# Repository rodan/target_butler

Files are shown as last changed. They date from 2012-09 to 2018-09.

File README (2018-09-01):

  Target butler is an archery-related project that tries to 'read' the arrow score based on sound and vibration sensor readouts.
  4 sensors (microphones) are surrounding the target itself, each of the 4 channels are amplified and the resulting signal passes thru an envelope-detection circuit. the 4 ADC values are read at a ~1ms interval by the uC.
  power is either from a 2Ah LiPo accu, any random 5V source or a solar panel.

  this project has not reached a 'working' stage. the sensors need to be changed to something that has a more omni-directional quality.

  Library dependencies for the included avr software:

  rfm12b      http://jeelabs.org/2009/02/10/rfm12b-library-for-arduino/
  sdfatlib    http://code.google.com/p/sdfatlib/

  dependencies for the server-side software:

  // not written yet

  Author:          Petre Rodan <2b4eda@subdimension.ro>
  Available from:  https://github.com/rodan/target_butler
  License:         GNU GPLv3

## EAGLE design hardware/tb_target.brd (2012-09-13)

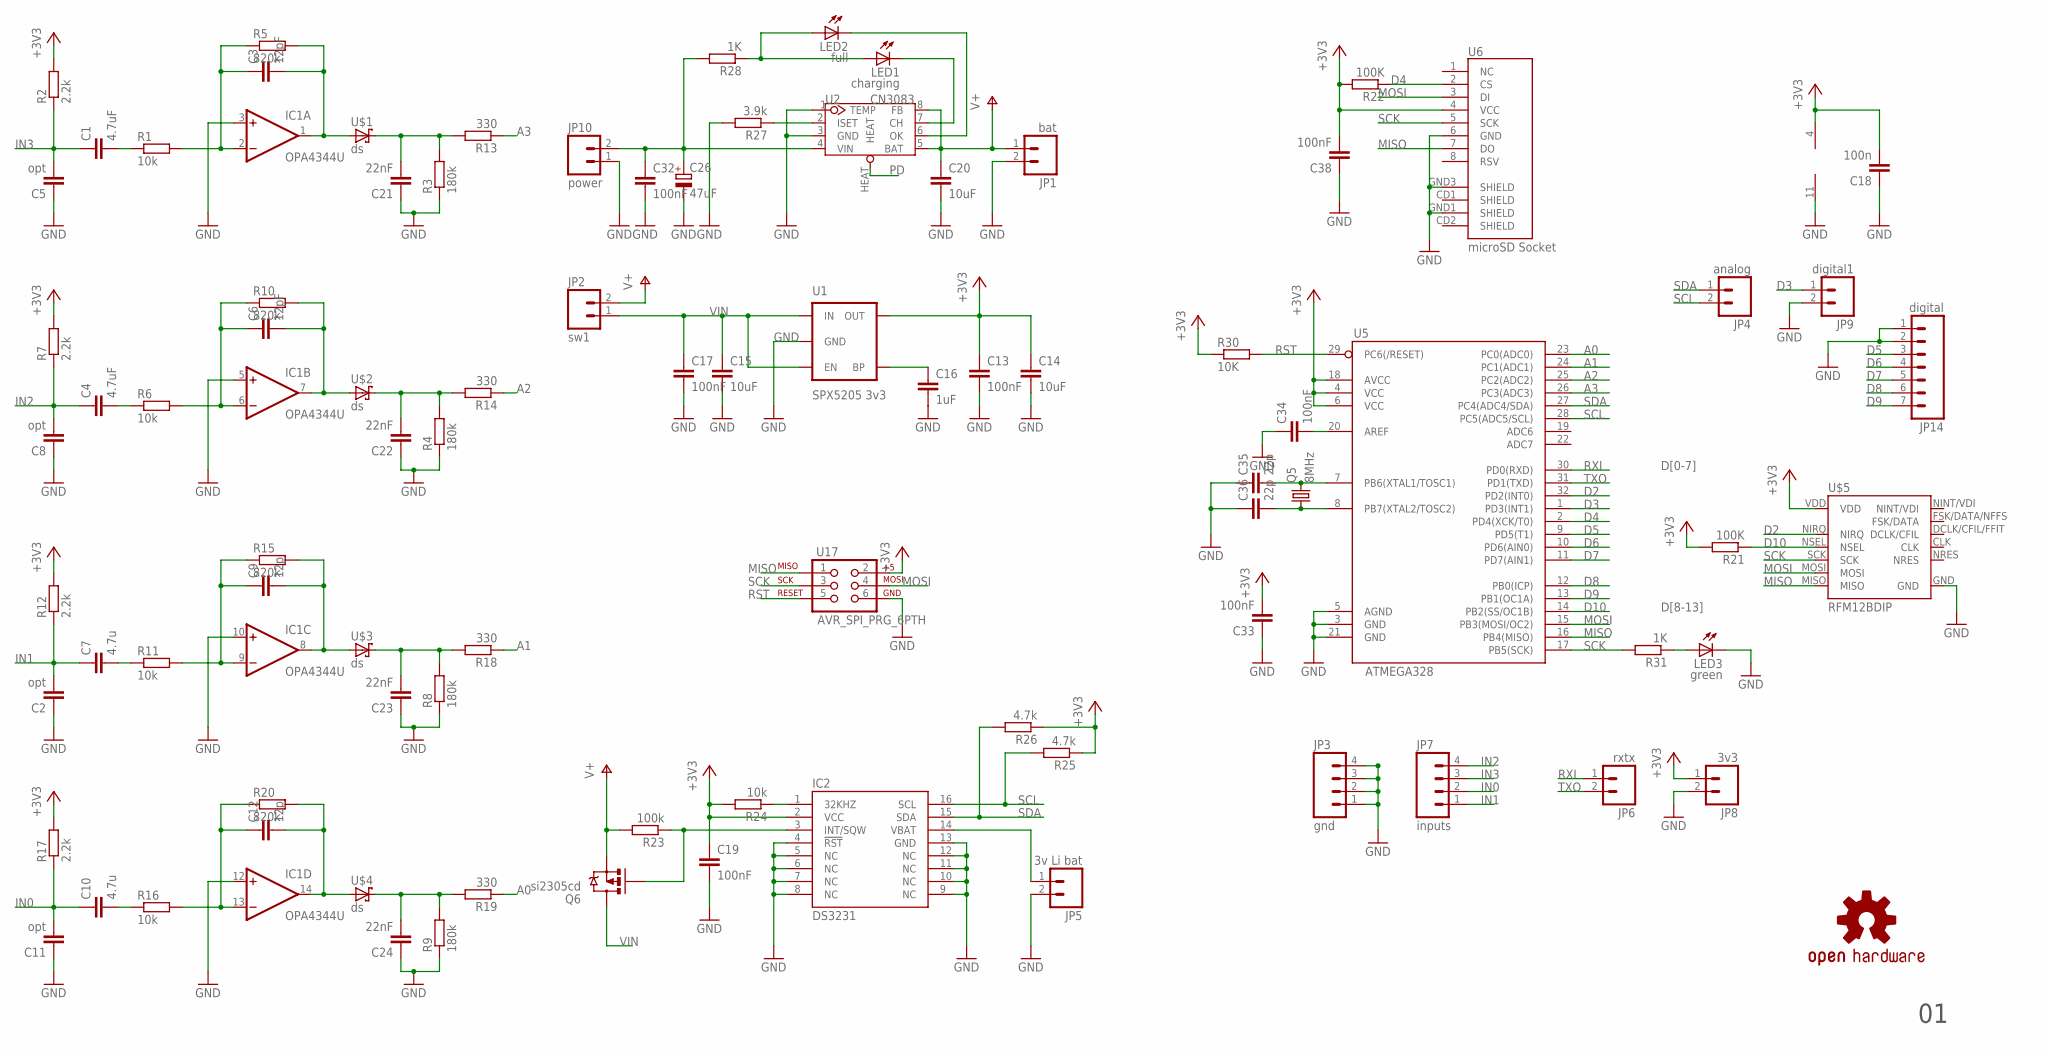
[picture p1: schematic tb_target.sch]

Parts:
C1, C4: 4.7uF; C0805
C2, C5, C8, C11: opt; C0805
C3, C6: 12pF; C0805
C7, C10: 4.7u; C0805
C9, C12: 12p; C0805
C13, C17, C19, C32, C33, C34, C38: 100nF; C0805
C14, C15, C20: 10uF; C1206
C16: 1uF; C0805
C18: 100n; C0805
C21, C22, C23, C24: 22nF; C0805
C26: 47uF; CT7343
C35, C36: 22p; C0805
IC1: OPA4344U; SO14
IC2: DS3231; SO-16
JP1: bat; 1X02
JP2: sw1; 1X02
JP3: gnd; 1X04
JP4: analog; 1X02
JP5: 3v Li bat; 1X02
JP6: rxtx; 1X02
JP7: inputs; 1X04
JP8: 3v3; 1X02
JP9: digital1; 1X02
JP10: power; 1X02
JP14: digital; 1X07
LED1: charging; CHIP-LED0805
LED2: full; CHIP-LED0805
LED3: green; CHIP-LED0805
Q5: 8MHz; CRYSTAL_5X3.2
Q6: si2305cd; SOT23-3_POWER
R1, R6, R11, R16, R24: 10k; R0805W
R2, R7, R12, R17: 2.2k; R0805W
R3, R4, R8, R9: 180k; R0805W
R5, R10, R15, R20: 820k; R0805W
R13, R14, R18, R19: 330; R0805W
R21, R22: 100K; R0805W
R23: 100k; R0805W
R25, R26: 4.7k; R0805W
R27: 3.9k; R0805W
R28, R31: 1K; R0805W
R30: 10K; R0805W
U1: SPX5205 3v3; SOT23-5
U2: CN3083; SOP8-W/-HEAT
U5: ATMEGA328; TQFP32-08
U6: microSD Socket; MICRO-SD-SOCKET-PP
U17: AVR_SPI_PRG_6PTH; 2X3
U$1, U$2, U$3, U$4: ds; SOD80
U$5: RFM12BDIP; RFM12B_DIP
U$7: OSHW-LOGOM; OSHW-LOGO-M

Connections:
+3V3: C13.1, C14.1, C18.2, C19.1, C33.2, C38.2, IC1.4 (V+), IC2.2 (VCC), JP8.1, R2.2, R7.2, R12.2, R17.2, R21.2, R22.2, R24.2, R25.1, R26.1, R30.1, U1.5 (OUT), U5.4 (VCC), U5.6 (VCC), U5.18 (AVCC), U6.4 (VCC), U17.2, U$5.VDD
A0: R19.1, U5.23 (PC0(ADC0))
A0D: C24.2, R9.2, R19.2, U$4.C
A1: R18.1, U5.24 (PC1(ADC1))
A1D: C23.2, R8.2, R18.2, U$3.C
A2: R14.1, U5.25 (PC2(ADC2))
A2D: C22.2, R4.2, R14.2, U$2.C
A2E: C6.2, IC1.7 (OUT), R10.2, U$2.A
A3: R13.1, U5.26 (PC3(ADC3))
A3D: C21.2, R3.2, R13.2, U$1.C
D2: U5.32 (PD2(INT0)), U$5.NIRQ
D3: JP9.1, U5.1 (PD3(INT1))
D4: R22.1, U5.2 (PD4(XCK/T0)), U6.2 (CS)
D5: JP14.3, U5.9 (PD5(T1))
D6: JP14.4, U5.10 (PD6(AIN0))
D7: JP14.5, U5.11 (PD7(AIN1))
D8: JP14.6, U5.12 (PB0(ICP))
D9: JP14.7, U5.13 (PB1(OC1A))
D10: R21.1, U5.14 (PB2(SS/OC1B)), U$5.NSEL
GND: C2.1, C5.1, C8.1, C11.1, C13.2, C14.2, C15.2, C16.2, C17.2, C18.1, C19.2, C20.2, C21.1, C22.1, C23.1, C24.1, C26.-, C32.2, C33.1, C34.1, C35.1, C36.1, C38.1, IC1.3 (+IN), IC1.5 (+IN), IC1.10 (+IN), IC1.11 (V-), IC1.12 (+IN), IC2.4 (!RST), IC2.5 (NC), IC2.6 (NC), IC2.7 (NC), IC2.8 (NC), IC2.9 (NC), IC2.10 (NC), IC2.11 (NC), IC2.12 (NC), IC2.13 (GND), JP1.2, JP3.1, JP3.2, JP3.3, JP3.4, JP5.2, JP8.2, JP9.2, JP10.1, JP14.1, JP14.2, LED3.C, R3.1, R4.1, R8.1, R9.1, R27.2, U1.2 (GND), U2.1 (TEMP), U2.3 (GND), U5.3 (GND), U5.5 (AGND), U5.21 (GND), U6.6 (GND), U6.GND1 (SHIELD), U6.GND3 (SHIELD), U17.6, U$5.GND
IN0: C10.1, C11.2, JP7.2, R17.1
IN1: C2.2, C7.1, JP7.1, R12.1
IN2: C4.1, C8.2, JP7.4, R7.1
IN3: C1.1, C5.2, JP7.3, R2.1
MISO: U5.16 (PB4(MISO)), U6.7 (DO), U17.1, U$5.MISO
MOSI: U5.15 (PB3(MOSI/OC2)), U6.3 (DI), U17.4, U$5.MOSI
unnamed: C16.1, U1.4 (BP)
unnamed: C1.2, R1.1
unnamed: C3.1, IC1.2 (-IN), R1.2, R5.1
unnamed: IC2.1 (32KHZ), R24.1
unnamed: IC2.3 (INT/SQW), Q6.1 (G), R23.1
unnamed: C4.2, R6.1
unnamed: C6.1, IC1.6 (-IN), R6.2, R10.1
unnamed: IC2.14 (VBAT), JP5.1
unnamed: R27.1, U2.2 (ISET)
unnamed: C7.2, R11.1
unnamed: C9.1, IC1.9 (-IN), R11.2, R15.1
unnamed: C26.+, C32.1, JP10.2, R28.2, U2.4 (VIN)
unnamed: LED1.A, LED2.A, R28.1
unnamed: C10.2, R16.1
unnamed: C12.1, IC1.13 (-IN), R16.2, R20.1
unnamed: LED1.C, U2.7 (CH)
unnamed: LED2.C, U2.6 (OK)
unnamed: C36.2, Q5.P$1 (1), U5.8 (PB7(XTAL2/TOSC2))
unnamed: C35.2, Q5.P$2 (2), U5.7 (PB6(XTAL1/TOSC1))
unnamed: C34.2, U5.20 (AREF)
unnamed: LED3.A, R31.1
unnamed: C3.2, IC1.1 (OUT), R5.2, U$1.A
unnamed: C9.2, IC1.8 (OUT), R15.2, U$3.A
unnamed: C12.2, IC1.14 (OUT), R20.2, U$4.A
PD: U2.HEAT
RST: R30.2, U5.29 (PC6(/RESET)), U17.5
RXI: JP6.1, U5.30 (PD0(RXD))
SCK: R31.2, U5.17 (PB5(SCK)), U6.5 (SCK), U17.3, U$5.SCK
SCL: IC2.16 (SCL), JP4.2, R25.2, U5.28 (PC5(ADC5/SCL))
SDA: IC2.15 (SDA), JP4.1, R26.2, U5.27 (PC4(ADC4/SDA))
TXO: JP6.2, U5.31 (PD1(TXD))
V+: C20.1, JP1.1, JP2.2, Q6.2 (S), R23.2, U2.5 (BAT), U2.8 (FB)
VIN: C15.1, C17.1, JP2.1, Q6.3 (D), U1.1 (IN), U1.3 (EN)

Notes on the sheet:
D[0-7]
D[8-13]

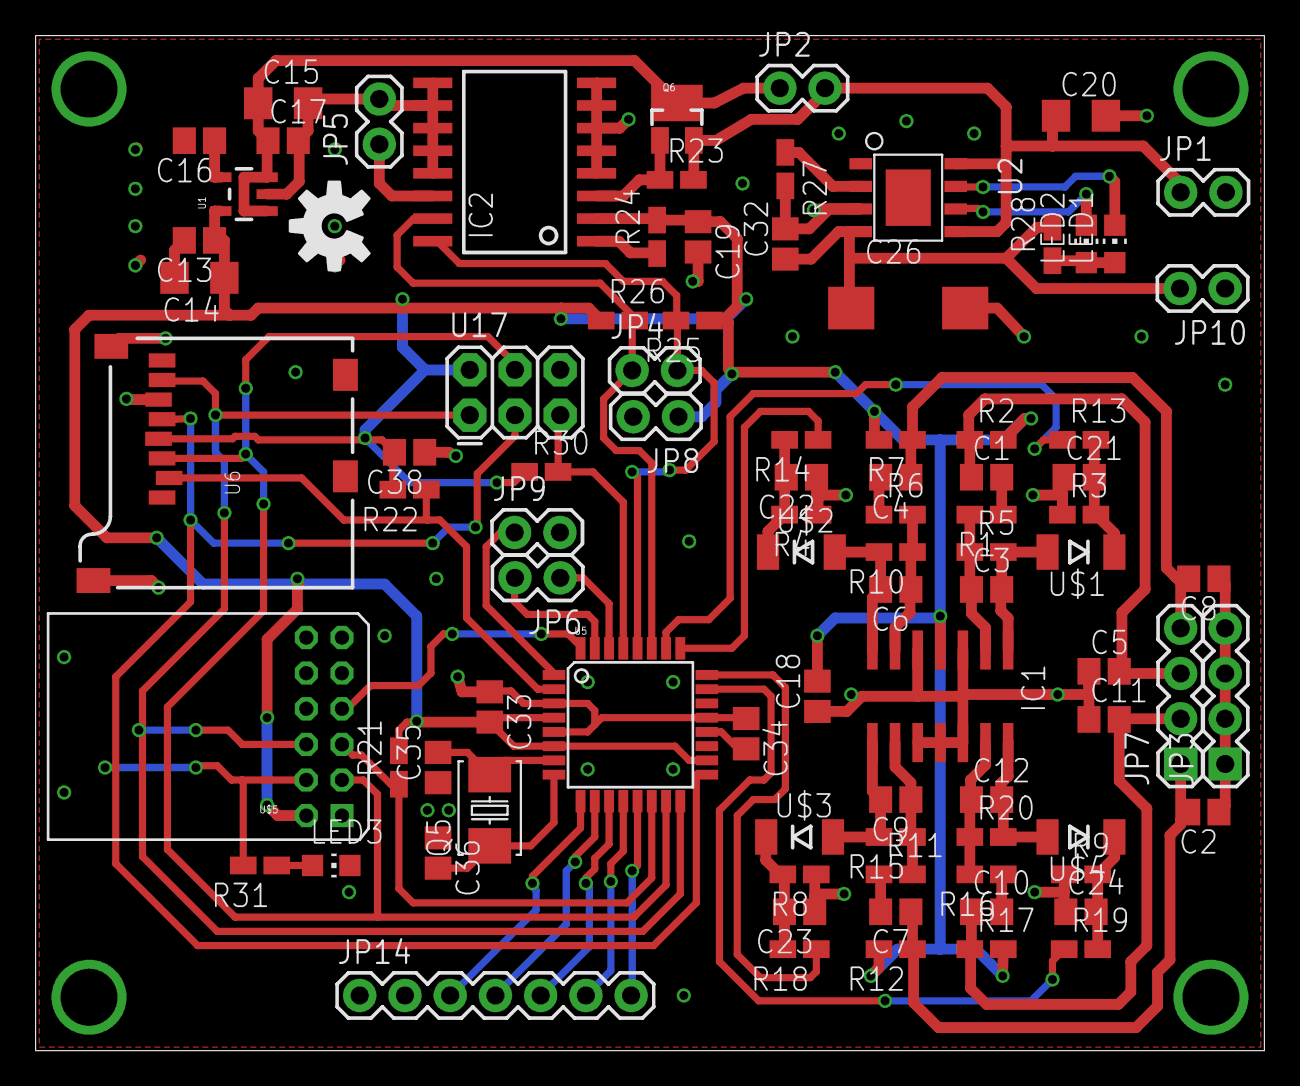
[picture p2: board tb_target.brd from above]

Board: 2 copper layers, 69.0 x 57.0 mm, 90 parts (0 on the bottom side), 58 nets.

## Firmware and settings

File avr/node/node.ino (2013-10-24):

#include <avr/wdt.h>
#include <SPI.h>
#include <SdFat.h>
#include <SdFatUtil.h>

//from jeelabs.org
#include <RF12.h>
#include <Ports.h>

#include "tb.h"

#define NODE_ID 10 // 0 to 29
#define FASTADC 0

#define pin_s0 A0
#define pin_s1 A1
#define pin_s2 A2
#define pin_s3 A3
#define pin_sd_cs 4

payload_result p;
payload_channel sen[4];

SdFat sd;
SdFile f;

int sample_delay = 1;

int threshold = 10;

// when to actually trigger the conversion
boolean adc_trigger = false;

// ADC conversion timeouts
unsigned long adc_conv_next = 2000;
// if a delay is needed before trigger computation
unsigned long adc_conv_trigger_timeout = 0;
unsigned long adc_delay_between_triggers = 400;

// USART timeouts
unsigned long refresh_prev = 0;
unsigned long refresh_delay = 400;

void discharge_inputs()
{
    // discharge the capacitor used for envelope detection
    pinMode(pin_s0, OUTPUT);
    pinMode(pin_s1, OUTPUT);
    pinMode(pin_s2, OUTPUT);
    pinMode(pin_s3, OUTPUT);
    digitalWrite(pin_s0, LOW);
    digitalWrite(pin_s1, LOW);
    digitalWrite(pin_s2, LOW);
    digitalWrite(pin_s3, LOW);
    delay(2);

    // go back into listening mode
    pinMode(pin_s0, INPUT);
    pinMode(pin_s1, INPUT);
    pinMode(pin_s2, INPUT);
    pinMode(pin_s3, INPUT);
}

void setup()
{
    uint8_t i;
    wdt_enable(WDTO_8S);

    delay(200); // allow 3v3 caps to fill up

    Serial.begin(9600);

#if FASTADC
    // set prescale to 16
    sbi(ADCSRA, ADPS2);
    cbi(ADCSRA, ADPS1);
    cbi(ADCSRA, ADPS0);
#endif

    if (!sd.init(SPI_HALF_SPEED, pin_sd_cs)) {
        Serial.println("ERR sd.init failed");
    }

    rf12_initialize(NODE_ID,freq,network);

    discharge_inputs();

    Serial.print("target butler node ");
    Serial.print(NODE_ID);
    Serial.println(" started");
    //Serial.println(sizeof p);

    p.node_id = NODE_ID;
    p.hit_id = 0;
    p.instant_en = 0;
    p.packet_type = PKT_RESULT;

    for (i=0; i<4; i++) {
        sen[i].packet_type = PKT_CHANNEL;
        sen[i].node_id = NODE_ID;
    }
}

void read_instant_en()
{
    p.instant_en =
        analogRead(pin_s0) + analogRead(pin_s1) + analogRead(pin_s2) + analogRead(pin_s3);

    discharge_inputs();
}

void read_inputs_multi()
{
    uint8_t i;

    for (i = 0; i < samples; i++) {
        sen[0].s[i] = analogRead(pin_s0);
        sen[1].s[i] = analogRead(pin_s1);
        sen[2].s[i] = analogRead(pin_s2);
        sen[3].s[i] = analogRead(pin_s3);
        //delay(sample_delay);
    }

    p.s_en[0] = 0;
    p.s_en[1] = 0;
    p.s_en[2] = 0;
    p.s_en[3] = 0;

    for (i = 0; i < samples; i++) {
        p.s_en[0] += sen[0].s[i];
        p.s_en[1] += sen[1].s[i];
        p.s_en[2] += sen[2].s[i];
        p.s_en[3] += sen[3].s[i];
    }
}

void loop()
{
    unsigned long now;
    uint8_t i,j;
    now = millis();
    wdt_reset();

    if (adc_trigger == true) {
        if (now > adc_conv_next) {
            read_inputs_multi();
            discharge_inputs();
            adc_trigger = false;
            // wait a while if this was a worthy trigger
            if (p.s_en[0] + p.s_en[1] + p.s_en[2] + p.s_en[3]  > 400) {
                adc_conv_next = now + adc_delay_between_triggers;
            } else {
                p.instant_en = 0;
            }
        }
    } else {
        if (now > adc_conv_next) {
            read_instant_en();
            if (p.instant_en > 200) {     // threshold
                adc_trigger = true;
                adc_conv_next = now + adc_conv_trigger_timeout;
            }
        }
    }

    if (now - refresh_prev > refresh_delay) {
        refresh_prev = now;
        //Serial.println(now);

        if (p.instant_en > 200) { // threshold
            f.open("trigger.log", O_RDWR | O_CREAT | O_AT_END);

            Serial.print(p.hit_id);
            Serial.print(" ");
            Serial.println(p.instant_en);
            f.print(p.hit_id);
            f.print(" ");
            f.println(p.instant_en);

            for (j = 0; j < 4; j++) {
                for (i = 0; i < samples; i++) {
                    Serial.print(sen[j].s[i]);
                    Serial.print(" ");
                    f.print(sen[j].s[i]);
                    f.print(" ");
                }
                Serial.println(p.s_en[j]);
                f.println(p.s_en[j]);
            }

            float result;
            int dr, st, max;

            dr=p.s_en[0];
            st=p.s_en[2];

            if (dr > st) {
                max=dr;
            } else {
                max=st;
            }

            Serial.println(dr);
            Serial.println(st);
            Serial.println(max);
            result = (dr-st)*100.0/max;
            Serial.print("result ");
            Serial.println(result);

            i = 0;
            while (!rf12_canSend() && i<10) {
                rf12_recvDone();
                i++;
            }
            rf12_sendStart(0, &p, sizeof p);
/*
            for (j = 0; j < 4; j++) {
                i = 0;
                while (!rf12_canSend() && i<10) {
                    rf12_recvDone();
                    i++;
                }
                rf12_sendStart(0, &sen[j], sizeof sen);
            }
*/
            p.instant_en = 0;
            discharge_inputs();
            f.close();
            p.hit_id++;
        }
    }
}

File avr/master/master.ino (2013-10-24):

//Simple RFM12B wireless demo - Receiver - no ack
//Glyn Hudson openenergymonitor.org GNU GPL V3 12/4/12
//Credit to JCW from Jeelabs.org for RFM12 

#include <avr/wdt.h>     // Include watchdog library
#include <JeeLib.h>

#include "tb.h"

uint8_t pkt_type;
payload_result p;

void setup() {
    delay(200);
    wdt_enable(WDTO_8S);   // Enable watchdog: max 8 seconds

    Serial.begin(9600); 

    rf12_initialize(30,freq,network);   //Initialize RFM12 with settings defined above  
  
    Serial.print(" Freq: "); 
    if (freq == RF12_433MHZ) Serial.print("433Mhz");
    if (freq == RF12_868MHZ) Serial.print("868Mhz");
    if (freq == RF12_915MHZ) Serial.print("915Mhz"); 
    Serial.print(" Network: "); 
    Serial.println(network);
}

void loop() {
    wdt_reset();           // Reset watchdog
  
    if (rf12_recvDone()){    
        if (rf12_crc == 0 && (rf12_hdr & RF12_HDR_CTL) == 0) {
            pkt_type=*(uint8_t*) rf12_data;
            switch (pkt_type) {
                case PKT_RESULT:
                    p=*(payload_result*) rf12_data;
                    Serial.print("node_id: "); Serial.println(p.node_id); 
                    Serial.print("hit_id: "); Serial.println(p.hit_id); 
                    Serial.print("instant_en: "); Serial.println(p.instant_en); 
                    Serial.print("hits: "); 
                    Serial.print(p.s_en[0]); 
                    Serial.print(" "); 
                    Serial.print(p.s_en[1]); 
                    Serial.print(" "); 
                    Serial.print(p.s_en[2]); 
                    Serial.print(" "); 
                    Serial.println(p.s_en[3]); 
                    Serial.println("  "); 
                break;
                default:
                    Serial.println("ERR unk_pck");
                break;
            }
        } else {
            Serial.println("ERR crc_err");
        }

    }
}

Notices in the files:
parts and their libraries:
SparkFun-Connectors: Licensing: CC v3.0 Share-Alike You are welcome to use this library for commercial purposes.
